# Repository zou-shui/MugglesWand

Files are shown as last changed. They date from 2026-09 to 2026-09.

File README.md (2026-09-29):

# Muggles' Wand - 基于TinyML的动力学手势分类魔杖

立创开源平台链接：[Muggles' Wand - 给麻瓜设计的魔杖 - 立创开源硬件平台](https://oshwhub.com/zoushui/project_zfbqlpxs)

## 项目简介

这是一根魔杖，但，是给麻瓜[^1]用的。

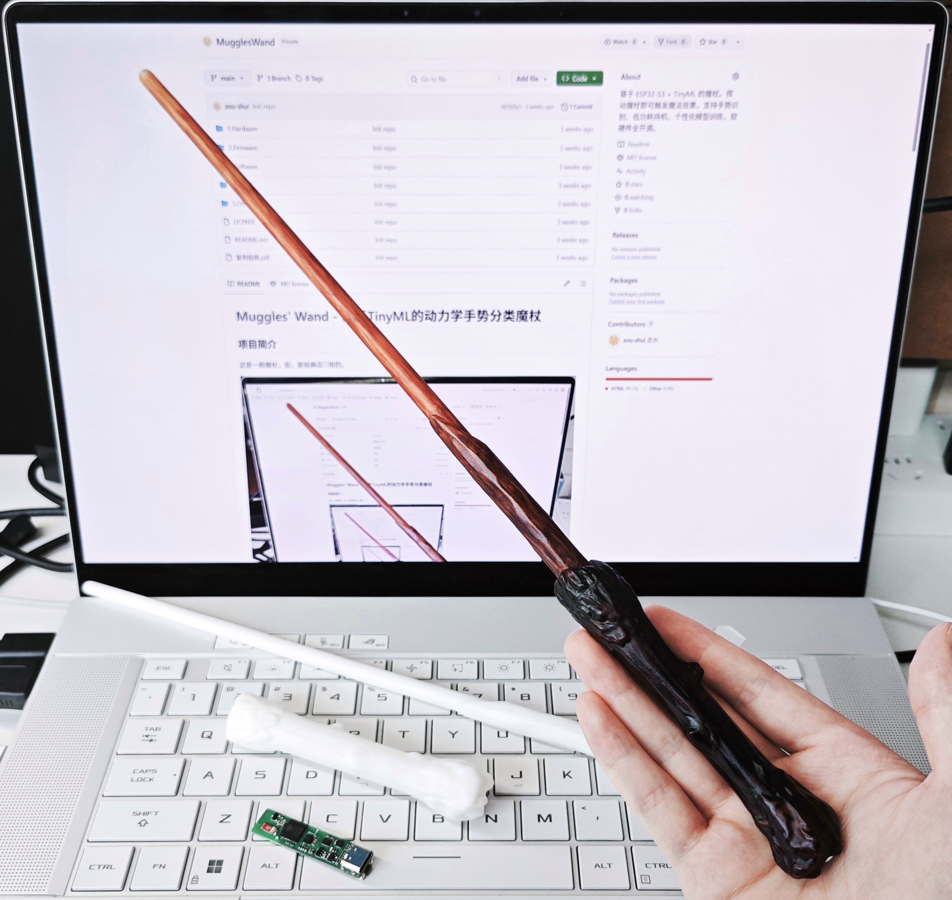
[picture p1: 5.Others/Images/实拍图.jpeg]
魔杖实物图


在哈利波特初代魔杖模型中嵌入ESP32-S3、六轴 IMU 和神经网络模型，麻瓜无需魔法，只需标准地挥动魔杖，即可触发专属的“魔法效果”（如Lumos[^2]、模拟键鼠、光绘效果等）。

## 视频链接

[【开源】给麻瓜的魔杖](https://www.bilibili.com/video/BV14XaJ6nEzr/?share_source=copy_web&vd_source=b9a966f3c62fa9746bb00910b5fc0d9c)

## 项目特点

- 哈利波特初代魔杖外形，内置RGB灯带提供施法光效。
- 基于ESP32-S3 + ICM42670P六轴 IMU，支持 Wi-Fi、BLE，便于扩展无线控制和交互功能。
- 精准电量 + 低功耗设计，静置待机，拿起开机，理论待机时间长达1.8年。
- 内置手势状态机自动区分有效手势和无意义挥动，无需提供显式手势开始(或结束)[^3]信号。
- 使用握持角度(姿势)无关变量训练模型，支持几乎任意握持姿角度/姿势。
- 配套上位机和魔杖Web端图形化界面，支持用户自行采集数据并训练个性化手势模型。

## 硬件架构

硬件由一块PCB + 电池 + 灯带组成。PCB集成了单片机、IMU、Type-C接口、按键以及跟电源相关的必要电路。

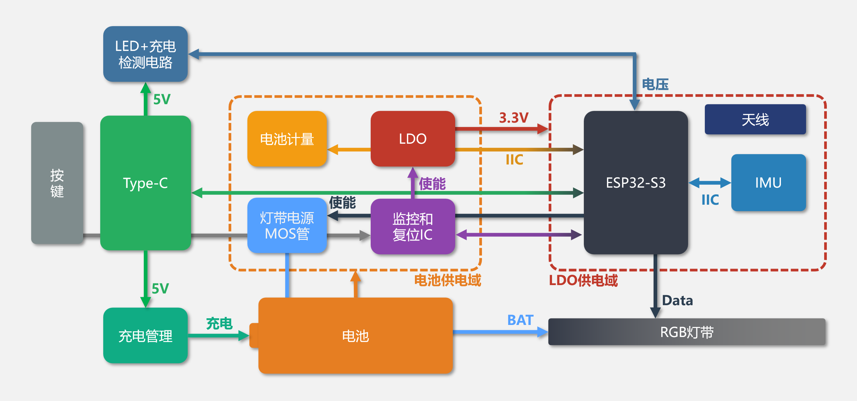
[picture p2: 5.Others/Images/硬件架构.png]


硬件位置关系及电气连接示意图如下。

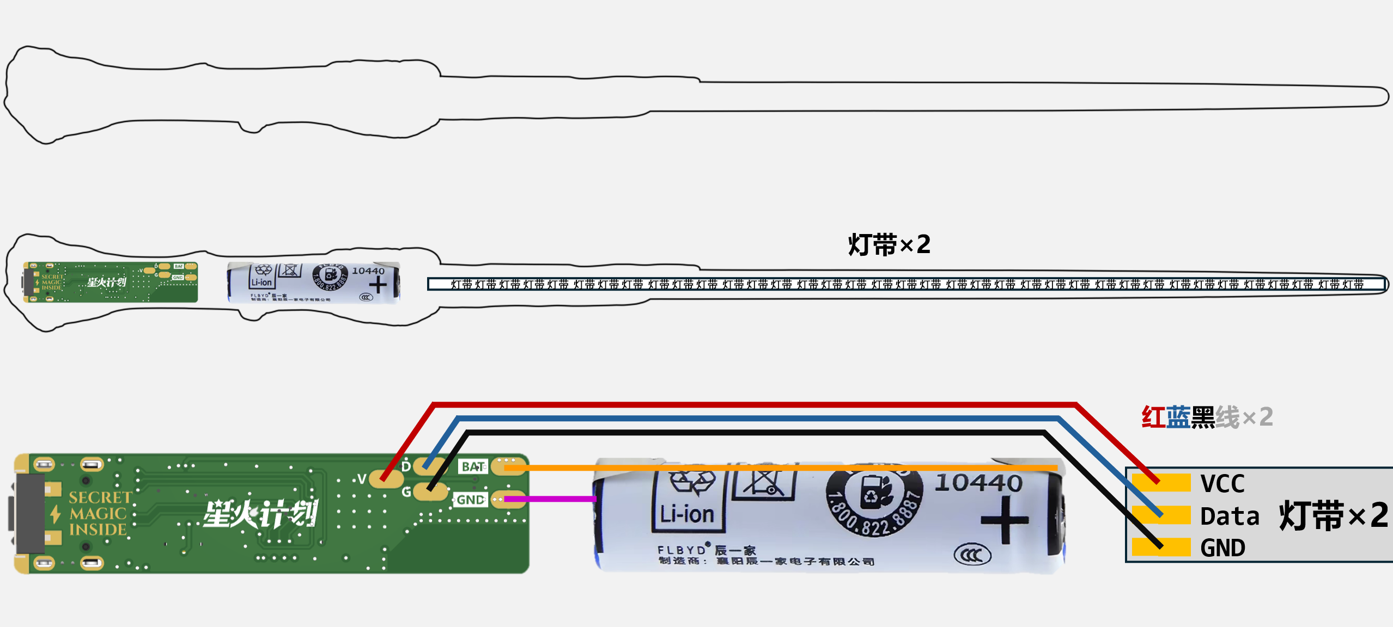
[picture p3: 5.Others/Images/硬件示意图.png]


## 使用方法

### 1. 基本操作

魔杖开机默认进入手势识别模式，固件内自带一个8分类的手势识别模型，识别如下手势：

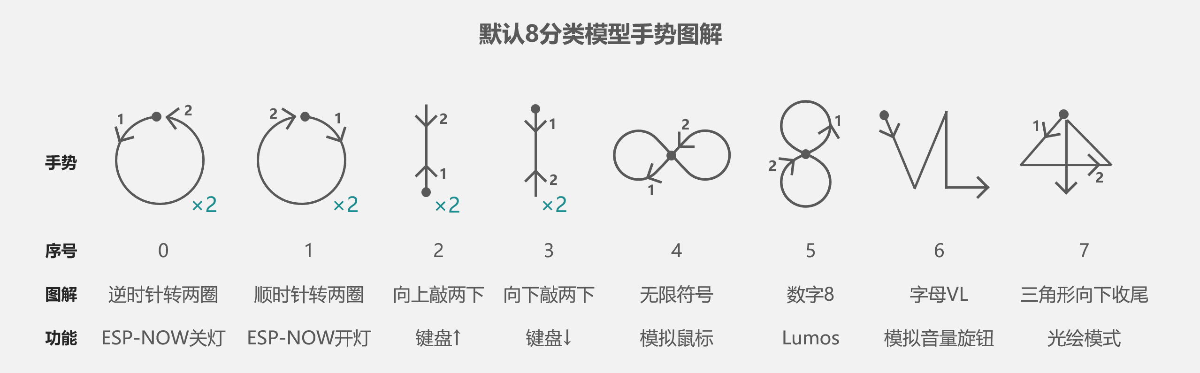
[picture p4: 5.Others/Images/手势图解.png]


只需要使用魔杖尖端在空中绘制出图形，就会触发对应的功能。挥动时间应≤1s，每个手势具体执行的功能可通过修改固件来自定义。

- ESP-NOW开关灯需要另一个接舵机的ESP32-S3开发板来执行动作，配套代码已开源在`2.Firmware`。
- 模拟键盘的按键可在固件中自定义。
- 光绘模式下，魔杖会持续检测加速度并自动触发光绘。

### 2. 按键操作

魔杖仅底部有一个按键，该按键承担了开机、关机、单击、双击、三击以及强制关机的功能。

- 关机时，单击按键开机。
- 开机时，长按按键1s关机；长按5s以上可强制断电关机[^4]。
- 开机时，单击按键的语义为“返回”，例如：模拟鼠标模式会占用IMU[^5]导致手势识别暂停，只需单击按键即可退出模拟鼠标模式。
- 双击、三击按键的行为可以在固件中自定义。

### 3. 使用命令操控魔杖

魔杖底部的 Type-C 接口连接 ESP32-S3 的USB虚拟串口(USB CDC)。将魔杖连接到 PC 后，通过串口助手与魔杖交互。可以像使用终端一样给魔杖发送命令，输入`help`获取可用命令，输入`ota`进入OTA模式。（下图左）

> 命令需要以回车符结尾才会被识别，另外需要打开串口助手的DTR和RTS才能通讯。

此外如果连接了魔杖的热点(AP)，还可以使用TCP/IP串口，地址192.168.4.1:8080（下图右）。

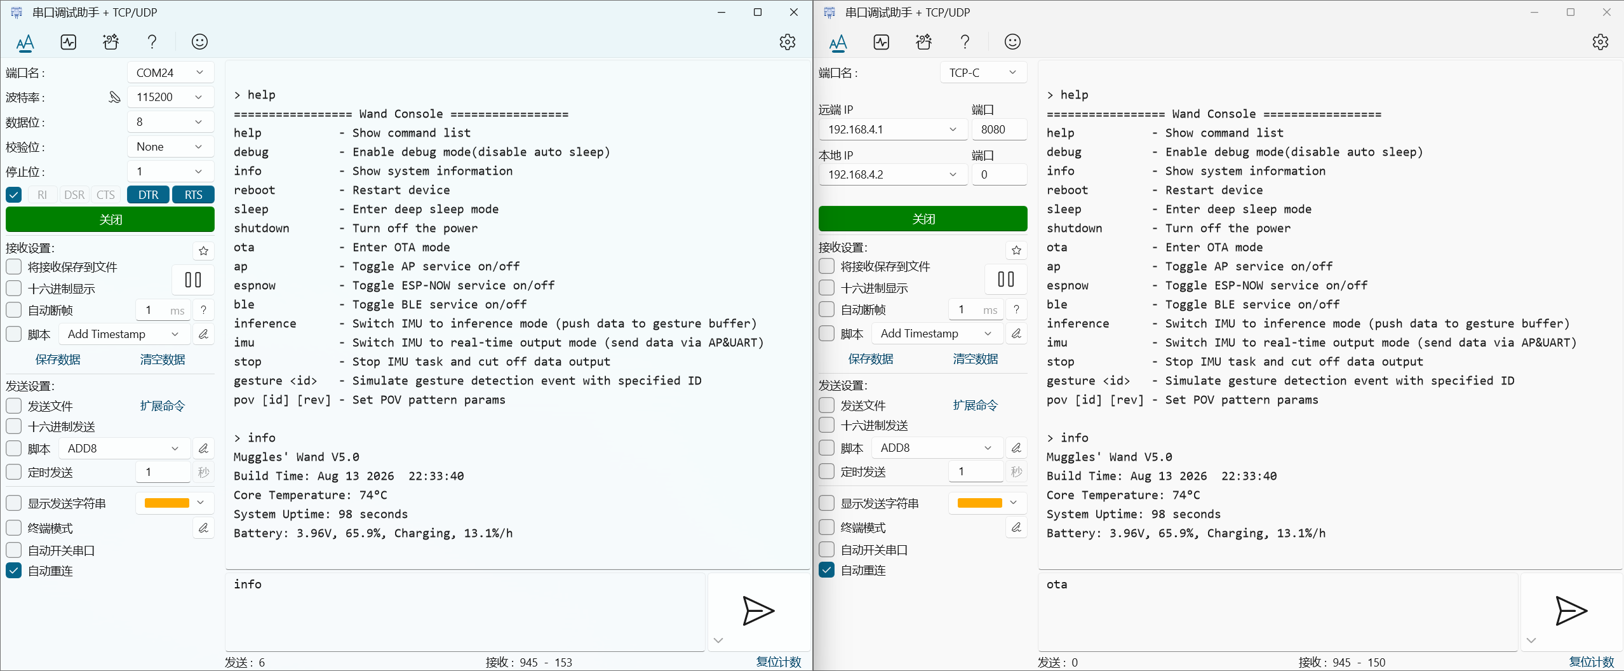
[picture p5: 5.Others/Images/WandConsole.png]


更进一步，连接魔杖热点情况下在浏览器中访问[192.168.4.1](http://192.168.4.1/)即可看到魔杖的Web端图形化界面，该界面功能和串口命令一致，但增加了IMU数据可视化。

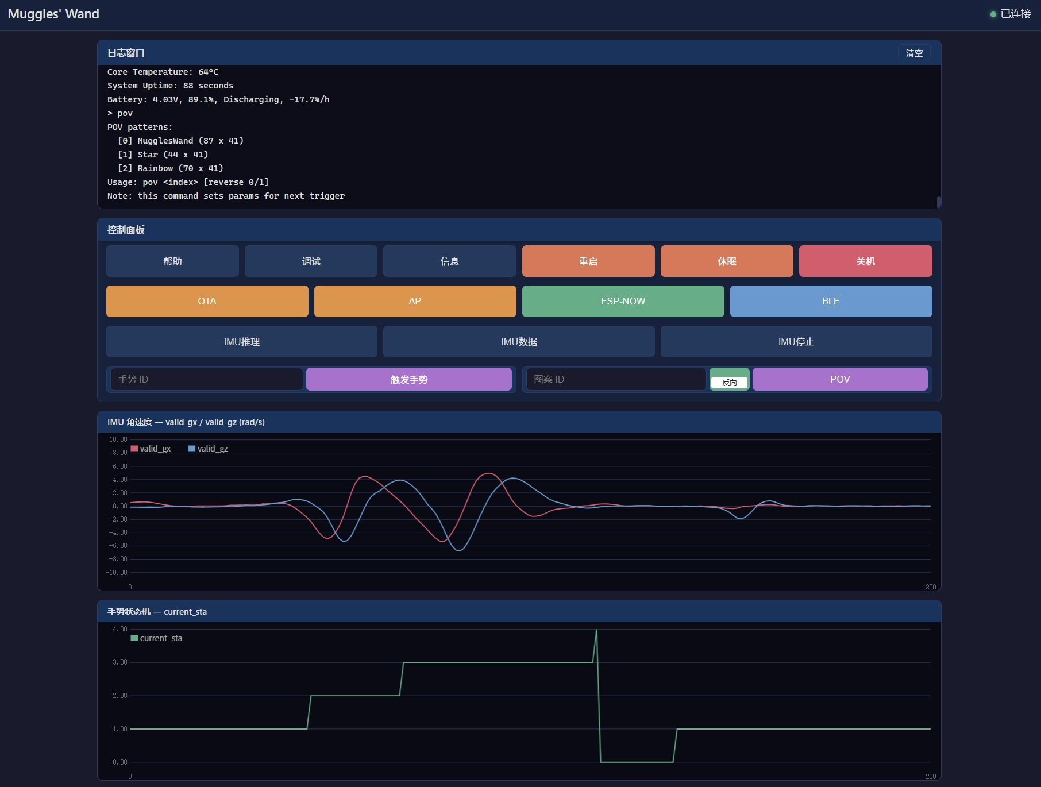
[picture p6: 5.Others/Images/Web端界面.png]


## 功耗分析

超低的待机功耗是本项目亮点之一。

在**待机状态**下，ESP32处于DeepSleep模式，系统处于运动唤醒模式，此时功耗如下表所示：

| 器件  | ESP32 | 复位IC | 电池计量 | IMU | LDO | 合计值（理论） | 实际 |
| --- | ----- | ---- | ---- | ----- | ----- | --- | ---- |
| 电流  | 7uA | 6uA  | 4uA  | 3.5uA | 1.8uA | 22.3uA  | 25uA |

实测待机功耗约 25 μA，在电池400mAh的可用容量下的理论待机时间约1.8年[^6]。

`400mAh / 0.025mA = 16000h ≈ 1.8年`

所有状态功耗情况如下表所示。

| 状态 | 功耗 | 备注 |
| --- | --- | --- |
| 关机 | 3uA | LDO输出关断，系统仅复位IC和电池计量IC耗电 |
| 待机 | 25uA | LDO输出使能，系统处于DeepSleep+运动唤醒状态 |
| 开机，关闭射频 | <100mA | - |
| 开机，开启射频 | <200mA | 实测续航约为2h |

由于灯带耗电量较高，故在光绘模式下续航可能无法达到2h。

## 上位机与模型训练

默认模型的训练数据有限，不同用户的挥动习惯可能导致识别准确率下降，也就是魔杖出现了“认主”现象。`3.Software`下提供数据采集工具和 TensorFlow 模型训练代码，用户可以自行采集数据并训练个性化模型，给魔杖“易主”。

另外，还提供将任意图片转换为光绘数组的上位机工具`POVTool`，自定义专属光绘图案。

## 复刻

由于固件源码以 Git 子模块方式管理，克隆项目时需要加上 `--recurse-submodules` 参数：

```bash
git clone --recurse-submodules https://github.com/zou-shui/MugglesWand.git
```

复刻可参考根目录下的[复刻指南.PDF](./复刻指南.pdf)，步骤包括硬件复刻、固件烧录、封装、上色和喷漆。

项目结构：

```
MugglesWand
 ├── 1.Hardware/      PCB工程、原理图、制版文件
 ├── 2.Firmware/      ESP32-S3固件及源码
 │   ├── MugglesWand-src/         魔杖源码（子仓库）
 │   ├── MugglesWand-firmware/    魔杖固件
 │   └── EspNow_Slave-src/        ESP-NOW舵机开关灯执行器源码
 ├── 3.Software/      数据采集、训练及上位机工具
 ├── 4.Model/         魔杖外壳模型
 ├── 5.Others/        数据手册、图片
 ├── 复刻指南.pdf
 └── README.md
```

[^1]: 麻瓜，英文Muggle，指不会魔法的普通人

[^2]: Lumos，魔杖照明咒，是一个可以点亮魔杖头、用来在黑暗中照明的魔咒

[^3]: 传统基于 IMU 的手势识别通常需要额外输入信号标记手势开始或结束。本项目通过手势状态机自动检测有效手势，从而无需额外的开始/结束按键。

[^4]: 强制关机是硬件级的，会直接关断LDO输出

[^5]: 不止模拟鼠标模式会占用IMU，模拟音量旋钮以及光绘模式都会占用IMU

[^6]: 魔杖所使用电池的额定容量为450mAh，但监控复位IC(STM6601)会在电池3.1V以下时关断LDO并无法再次开机，所以估计电池可用容量为400mAh。另外由于电池自放电等因素影响，实际待机时间可能会更短。

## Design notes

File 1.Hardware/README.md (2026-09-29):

# Hardware

本目录存放PCB工程文件、Gerber文件、原理图以及BOM表。

工程文件后缀名为`.epro2`，使用立创EDA专业版打开，打开方式为：文件 -> 导入 -> 嘉立创EDA专业版。

## 下单注意事项

板厚务必选择**1.0mm**；另外天线的走线做了50Ω阻抗匹配，下单时请按照图中红框选择。

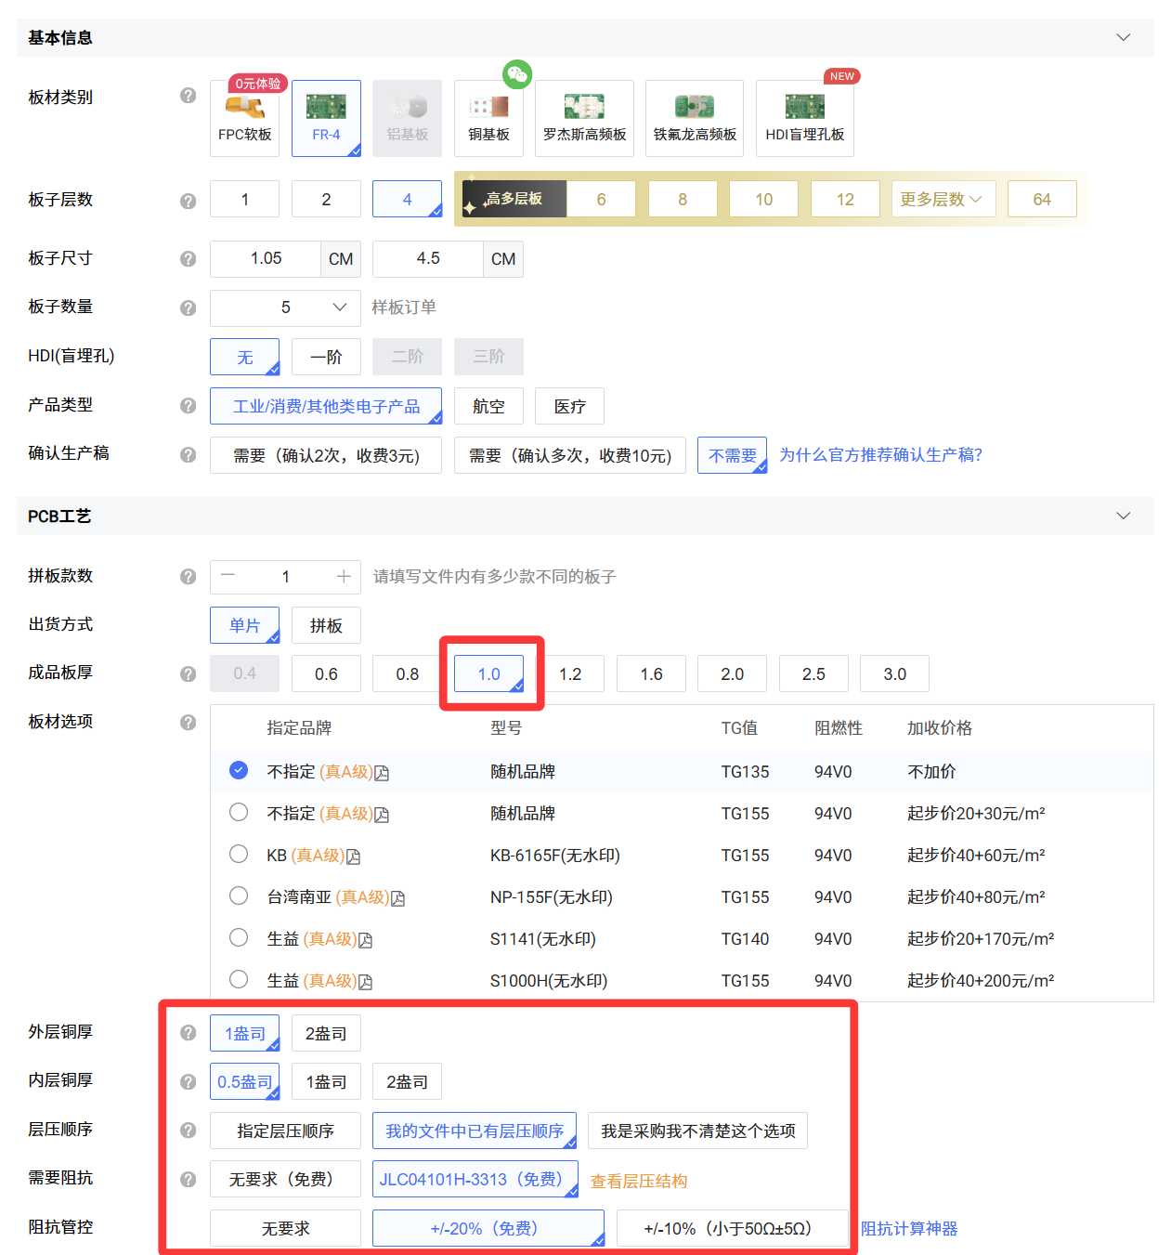
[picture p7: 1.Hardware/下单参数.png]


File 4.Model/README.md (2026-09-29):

# Model

本目录存放魔杖的模型文件，包含Blender原工程和导出的STL文件，可直接使用STL文件进行3D打印。

## 下单注意事项

使用以下参数打印

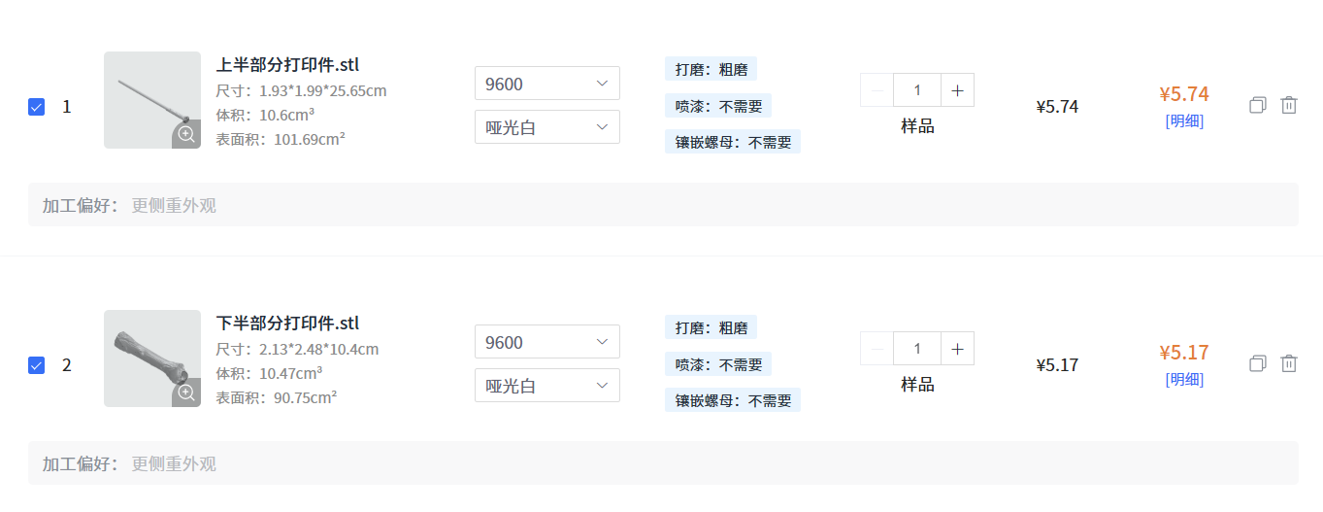
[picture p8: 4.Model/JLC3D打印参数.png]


另外由于**上半部分打印件**为细长中空盲孔模型，打印件可能会出现以下问题：

* 因模型45°摆放打印导致**打印件弯曲**

* 中空部分**残留树脂**，导致灯带无法塞入

为尽可能避免上述问题，请在下单前备注以下内容：

```
上半部分打印件需要竖直摆放进行打印，发货前请确保中空孔洞内干净无残留液体。
下半部分打印件无特殊要求。
```

## 模型说明

魔杖模型来源于[🪄 harry potter magic wand prop・Free OBJ File for ・Cults](https://cults3d.com/en/3d-model/game/harry-potter-magic-wand-prop)，经过微调、切割和挖空之后导出为STL文件，具体可查看Blender工程。

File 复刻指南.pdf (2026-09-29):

# Muggles’ Wand

# 复刻指南

# VERSION: 2026-9-29 Copyright © 2026 zoushui

感谢您对本项目的支持！Muggles’ Wand 以哈利波特使用的初代魔杖模型为原型，使用 光固化 3D 打印魔杖实体，在其内嵌入现代科技制成。因为是给麻瓜制作的魔杖，故命名为

## Muggles’ Wand。

复刻有一定的难度，建议通览整个项目资料、确定可行性之后再开始。

1 准备工作

正式开始制作前，请准备以下工具、材料及电子元器件。

准备工具：加热台及锡膏、电烙铁及焊锡丝、镊子、502 胶水、704 有机硅密封胶。

## 1. PCB 打样，板厚选择 1.0mm。

2. 根据 BOM 表购买所需元器件。
3. 打印魔杖模型，打印材料选树脂 9600。
4. 购买锂电池、漆包线、灯带，其具体参数如下：
物料 | 参数 | 实物图

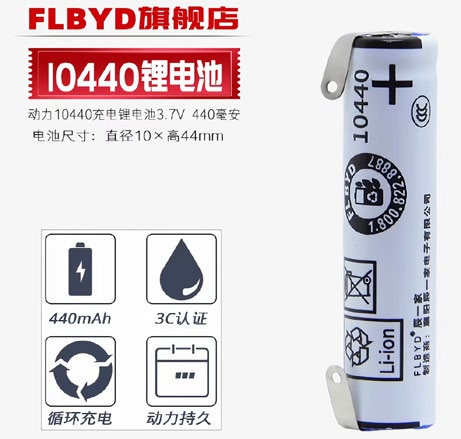
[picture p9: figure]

锂电池

额定电压 3.7V
尺寸 10440

## (直径 10mm 长度 44mm)

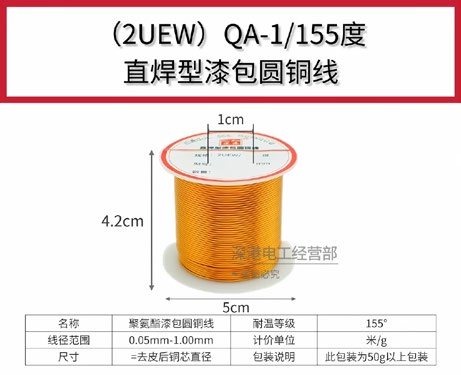
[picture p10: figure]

## QA 漆包线 直径 0.3mm

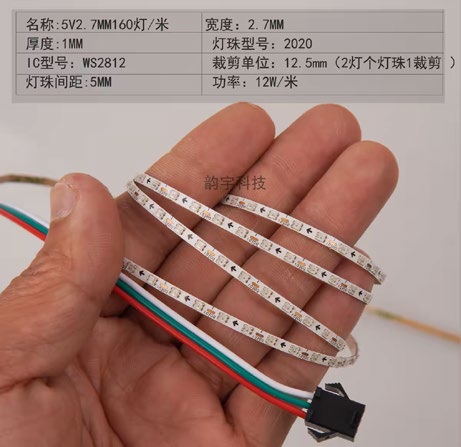
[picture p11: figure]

WS2812
可编程灯带

额定电压 5V

## 宽度 2.7mm

灯珠密度 160 灯/米

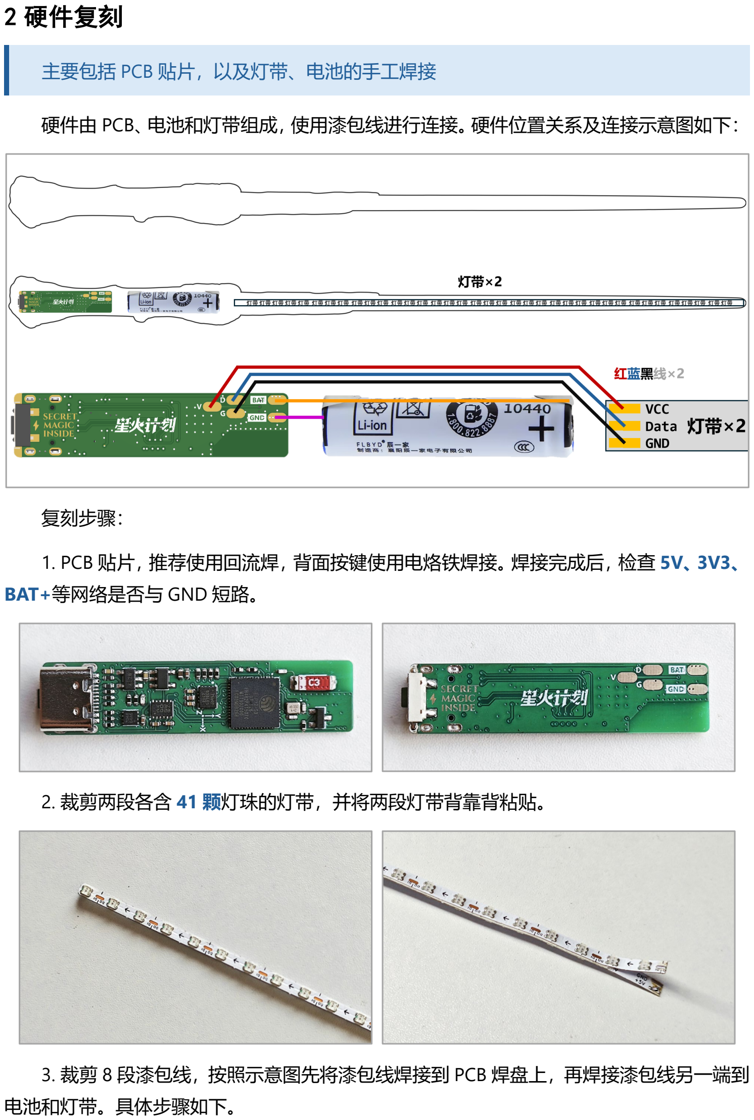
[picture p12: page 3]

2 硬件复刻

主要包括 PCB 贴片，以及灯带、电池的手工焊接

硬件由 PCB、电池和灯带组成，使用漆包线进行连接。硬件位置关系及连接示意图如下：

复刻步骤：
1. PCB 贴片，推荐使用回流焊，背面按键使用电烙铁焊接。焊接完成后，检查 5V、3V3、 BAT+等网络是否与 GND 短路。
2. 裁剪两段各含 41 颗灯珠的灯带，并将两段灯带背靠背粘贴。
3. 裁剪 8 段漆包线，按照示意图先将漆包线焊接到 PCB 焊盘上，再焊接漆包线另一端到 电池和灯带。具体步骤如下。

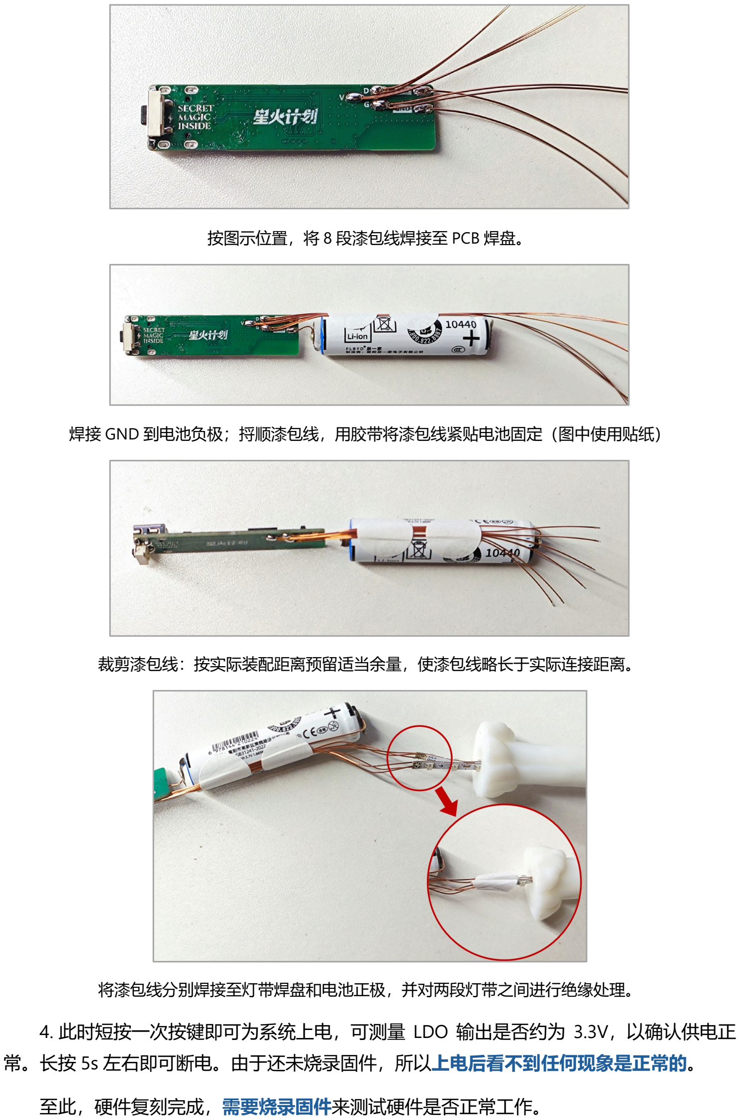
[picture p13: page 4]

按图示位置，将 8 段漆包线焊接至 PCB 焊盘。

焊接 GND 到电池负极；捋顺漆包线，用胶带将漆包线紧贴电池固定（图中使用贴纸）

裁剪漆包线：按实际装配距离预留适当余量，使漆包线略长于实际连接距离。

将漆包线分别焊接至灯带焊盘和电池正极，并对两段灯带之间进行绝缘处理。
4. 此时短按一次按键即可为系统上电，可测量 LDO 输出是否约为 3.3V，以确认供电正 常。长按 5s 左右即可断电。由于还未烧录固件，所以上电后看不到任何现象是正常的。

至此，硬件复刻完成，需要烧录固件来测试硬件是否正常工作。

3 固件烧录

向 ESP32 内烧录固件并测试硬件是否正常

使用 USB 烧录前，确保电池已连接，且系统处于关机状态（LDO 无 3.3V 输出）。使用镊 子将按键外壳的金属部分（BOOT）与 GND 短接，例如接触 Type-C 外壳。保持短接，同时短 按按键使 ESP32 上电。随后通过 USB 连接 PC，设备管理器出现新的串口号后即可开始烧录。

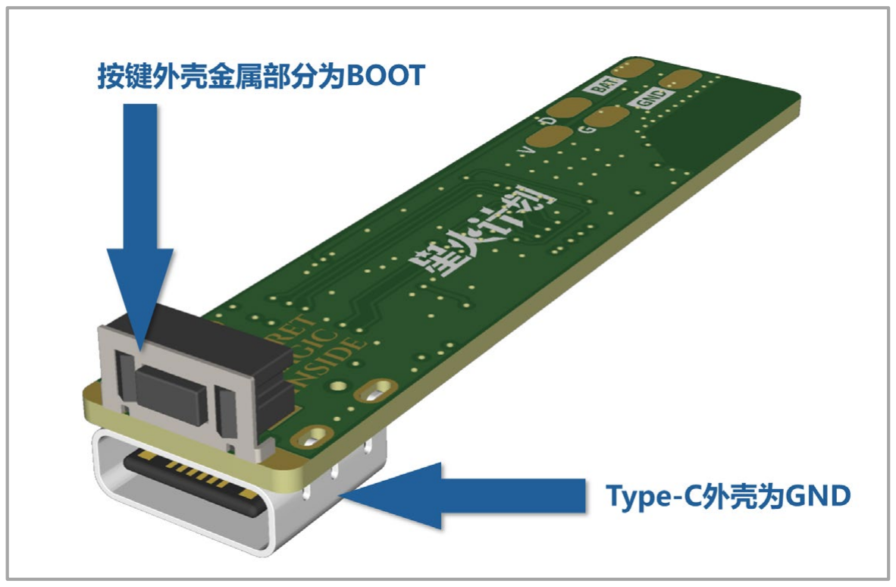
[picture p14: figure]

有两种烧录方式可选择，推荐使用 PlatformIO 烧录。

- PlatformIO 烧录：点击烧录按钮，PlatformIO 通常会自动识别设备串口并开始烧录。

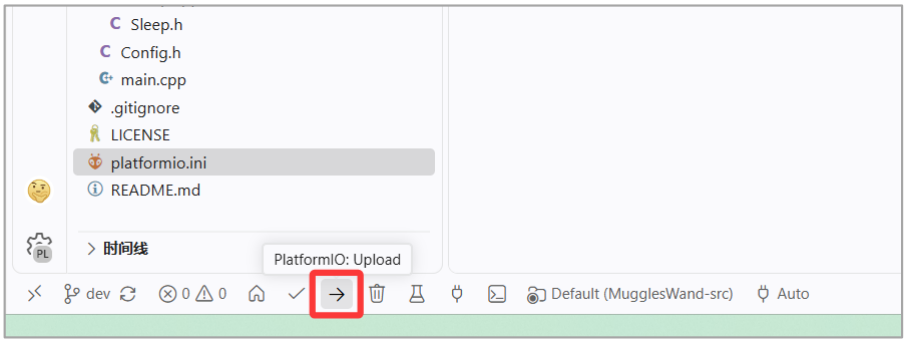
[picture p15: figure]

- 使用烧录工具烧录：使用乐鑫官方烧录工具 flash_download_tool(点击跳转下载链接) (https://docs.espressif.com/projects/esp-test-tools/zh_CN/latest/esp32/production_stage/tools/flash_download_tool.html)

## 烧录 2.Firmware/MugglesWand-firmware 下的三个 bin 文件，该文件夹下附带有具体操作截

图可参考。另外可参考官方的烧录步骤。 (https://docs.espressif.com/projects/esp-test-tools/zh_CN/latest/esp32/production_stage/tools/flash_download_tool.html)
固件烧录完成后，长按按键 5s 以上关机，再短按开机，程序即可运行。需要测试硬件和 各功能是否正常，都正常即可进入下一步封装。

由于封装过程不可逆，故需要确保硬件和功能全部正常才可以进入下一步封装。

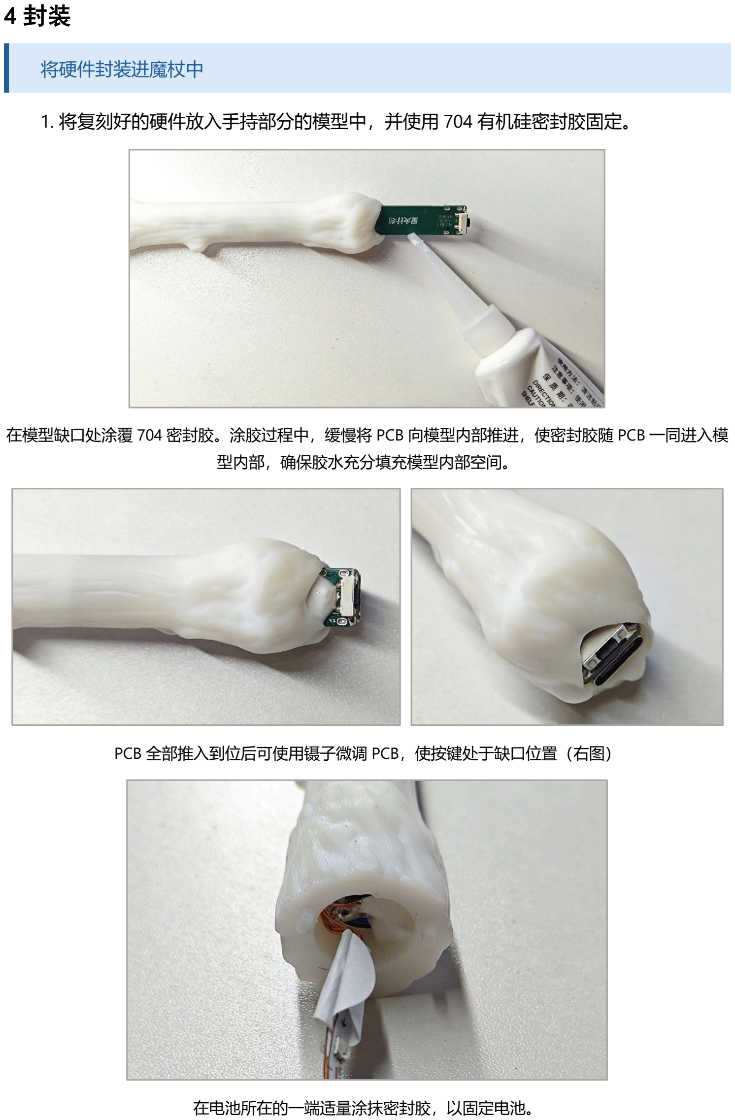
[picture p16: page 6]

4 封装

将硬件封装进魔杖中

1. 将复刻好的硬件放入手持部分的模型中，并使用 704 有机硅密封胶固定。

在模型缺口处涂覆 704 密封胶。涂胶过程中，缓慢将 PCB 向模型内部推进，使密封胶随 PCB 一同进入模 型内部，确保胶水充分填充模型内部空间。

PCB 全部推入到位后可使用镊子微调 PCB，使按键处于缺口位置（右图）

在电池所在的一端适量涂抹密封胶，以固定电池。

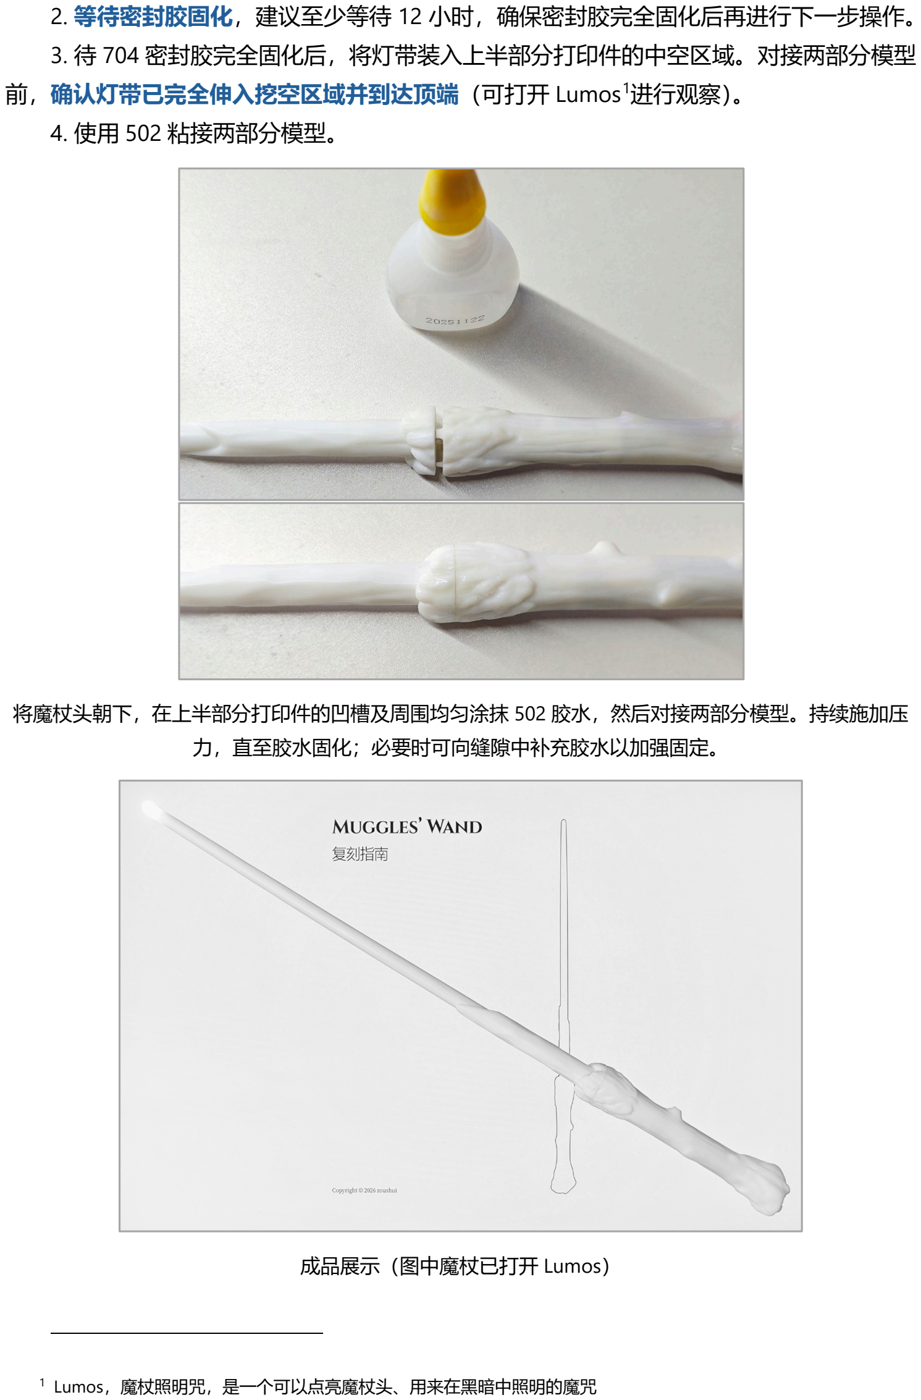
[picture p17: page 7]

2. 等待密封胶固化，建议至少等待 12 小时，确保密封胶完全固化后再进行下一步操作。
3. 待 704 密封胶完全固化后，将灯带装入上半部分打印件的中空区域。对接两部分模型 前，确认灯带已完全伸入挖空区域并到达顶端（可打开 Lumos¹
进行观察）。
4. 使用 502 粘接两部分模型。

将魔杖头朝下，在上半部分打印件的凹槽及周围均匀涂抹 502 胶水，然后对接两部分模型。持续施加压 力，直至胶水固化；必要时可向缝隙中补充胶水以加强固定。

成品展示（图中魔杖已打开 Lumos）

1 Lumos，魔杖照明咒，是一个可以点亮魔杖头、用来在黑暗中照明的魔咒

5 魔杖上色及喷漆

为封装好的魔杖上色和喷漆

封装完成之后，魔杖已经可以使用了，如需进一步提高还原度，可对模型进行上色。以 下上色及喷漆方案经过实际验证，可供参考。

5.1 模型上色
使用棕色系油性马克笔上色（更贴近木头的颜色）。需要 3 种由浅到深的棕色系马克笔， 从魔杖头到手持部分颜色逐渐变深。

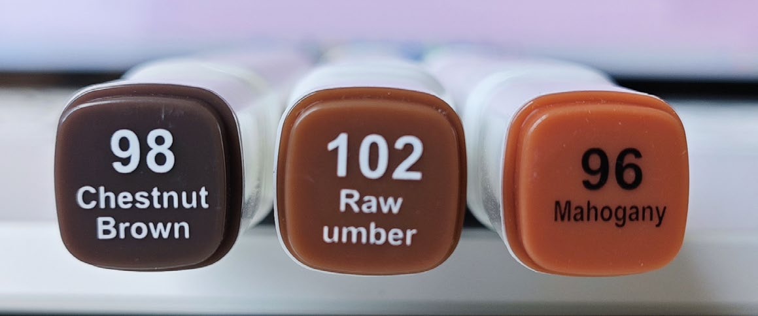
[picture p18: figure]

色号供参考
为了尽可能减小对”Lumos”亮度的影响，推荐魔杖头只上一层薄薄的颜料即可。

5.2 模型喷漆
使用油性马克笔上色完成后，等待其充分干燥。即使表面已经干燥，油性马克笔涂层仍 可能出现黏手、掉色等情况，这与其涂层特性有关。推荐使用 B603 水性消光透明保护漆在 外部喷一层漆，可以解决掉色和黏手的问题。

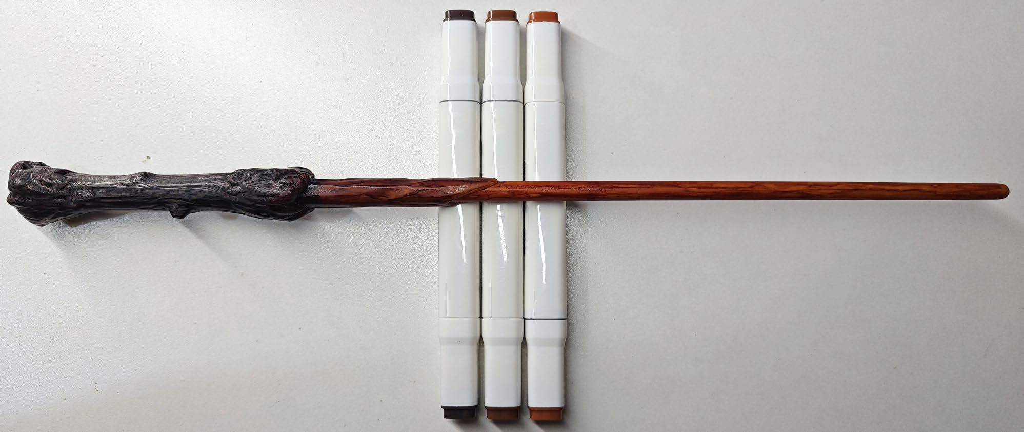
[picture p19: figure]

成品展示

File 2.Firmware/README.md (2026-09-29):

# Firmware

本目录存放 Muggles' Wand 固件及源码，源码`MugglesWadn-src`请参见子仓库[MugglesWand-src](https://github.com/zou-shui/MugglesWand-src)。

`MugglesWand-firmware`文件夹下存放子仓库**main分支**中最新的代码编译的固件，烧录方式请参考`复刻指南.PDF`第3节内容。

`EspNow_Slave-src`为基于ESP-NOW的舵机开关灯执行器的源码，运行在一块ESP32-S3-Zero开发板上。

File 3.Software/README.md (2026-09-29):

# Software

本目录存放在PC上运行的Python脚本和tf模型

## 1.OriginalData

内有DataCollector脚本源码以及打包好的可执行文件`DataCollector.exe`，后者可直接运行（无需Python环境）。

另外附有固件中模型的原始数据（csv）。

## 2.TensorFLow

内有利用原始数据对模型进行训练的程序`train.py`。需要自行配置python环境后运行。详细步骤请参阅内部的`README.md`。

## 3.POVTool

该工具是一个带有UI的可视化上位机，用于将任意图片转换成数组，供光绘模块使用。需要自行配置python环境后运行，详细步骤请参阅内部的`README.md`。

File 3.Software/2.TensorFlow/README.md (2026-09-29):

# train.py 简介

`train.py` 用于训练手势识别模型，主要特点：

- **自动识别数据集**：自动读取同目录下所有 `N.csv` 文件（`N` 为从 0 开始连续的整数），文件名即手势类别编号，支持自定义任意数量的手势类别。
- **数据格式**：每行一个样本，格式为 `label, x0, y0, x1, y1, …, x99, y99`，即 100 个时刻的 2 轴数据；脚本会校验行内标签与文件名一致，不符则终止。
- **网络结构**：轻量 1D-CNN（2 层卷积 + 批归一化 + 池化 + 全连接），配合 EarlyStopping 防止过拟合，PC 上即可快速训练。
- **自动量化**：训练完成后自动转为 INT8 全整数量化模型 `gesture_model.tflite`，并在终端输出归一化参数 `mean` / `std`，供固件端推理使用。

## 运行脚本

TensorFlow需要python3.9，需先安装该版本的Python。

用python3.9创建虚拟环境：

```bash
py -3.9 -m venv tf_env
```

激活虚拟环境：

```bash
tf_env\Scripts\activate
```

安装依赖：

```bash
pip install -r requirements.txt
```

运行脚本（运行之前请先将训练数据放在train.py同级目录）：

```bash
python train.py
```

模型训练好后会输出归一化参数`mean`和`std`到终端、生成模型文件`gesture_model.tflite`到根目录。后者需要在git bash中使用以下命令将其转换为字节数组：

```bash
xxd -i gesture_model.tflite > gesture_model.h
```

之后即可替换原固件中的模型，需要替换的地方有：

`src/Model/gesture_inference.cpp`中的**归一化参数**和**输出类别数量**

`src/Model/gesture_model.h`整个文件替换为新的`gesture_model.h`

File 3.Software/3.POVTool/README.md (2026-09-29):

# MugglesWand POV 光绘图案生成器（上位机）

把任意图片转换为固件 POV 光绘模块（`src/APP/APP_POVPatterns.h`）所需的
`CRGB[rows][cols]` 图案数组，并实时预览点阵效果与魔杖挥舞路径。

## 目录结构

```
POVTool/
├── main.py              # 入口: python main.py
├── gui.py               # PySide6 界面（点阵预览 + 挥舞动画）
├── core.py              # 转换核心: 加载/去背景/缩放/方向映射/自动比例
├── exporter.py          # CRGB 代码生成 + 固件头文件插入
├── requirements.txt
└── wand_lineart.png     # 挥舞动画素材（灯带区域: 横向像素 x=30~1310）
```

## 运行上位机

**1.（可选）创建虚拟环境**

虚拟环境可隔离本项目依赖，避免污染系统 Python；跳过此步则直接全局安装。

```bash
python -m venv .venv
```

激活虚拟环境（Windows）：

```bash
.venv\Scripts\activate
```

> 激活后命令行提示符前会出现 `(.venv)`；之后步骤的命令均在虚拟环境中执行。

**2. 安装依赖**

```bash
pip install -r requirements.txt
```

**3. 启动上位机**

```bash
python main.py
```

## 上位机使用说明

1. **导入图片**：点击「选择图片…」或直接拖入窗口（支持 PNG/JPG/BMP/WebP/GIF）。
   导入时按图片宽高比自动调整行数，并自动开始播放预览（100% 速度 = 固件 10ms/帧）。
2. **图案参数**：
   - **图案名**：仅限英文/数字/下划线（C 标识符），含中文会实时警告
   - **列数(LED)**：灯带 LED 数量，固件固定为 41；改变列数时行数按比例联动
   - **行数(帧)**：播放帧数，决定图案高度与播放时长（行数 × 10ms）
   - **扫描方向**：杖水平从上往下挥 / 杖竖直从左往右挥，切换时按图片比例动态调整行数
   - **左右镜像**：杖水平时 LED 列反序；杖竖直时改为从右往左挥
   - **去除背景**：取四角平均色，容差内视为透明（白底/纯色底图片常用）
3. **预览**：「挥舞动画」页用 `wand_lineart.png` 渲染真实的挥舞路径与拖尾；「点阵预览」页显示空间效果图案。
4. **导出**：
   - **复制 CRGB 代码**：图案块 + 注册行，格式与 `APP_POVPatterns.h` 一致
   - **保存完整头文件**：可直接编译
   - **插入固件头文件**：一键写入，自动备份 `.bak`，同名图案整体替换

## 打包成 exe（分发到无 Python 的电脑）

**1.（可选）创建虚拟环境**（同上；已创建过可跳过）

```bash
python -m venv .venv
.venv\Scripts\activate
```

**2. 安装 PyInstaller**

```bash
pip install pyinstaller
```

**3. 打包**

```bash
pyinstaller --noconfirm --clean --onefile --windowed --name MugglesWandPOVTool --add-data  "wand_lineart.png;." main.py
```

产物：`dist/MugglesWandPOVTool.exe`（单文件，约 65MB），目标电脑无需安装
Python，双击即用。

要点：

- `--onefile` 单文件模式（首次启动解压稍慢）；若在意启动速度或杀毒误报，
  可换成 `--onedir` 目录模式
- `--windowed` 隐藏控制台窗口
- 挥舞动画素材 `wand_lineart.png` 已通过 `--add-data` 打进 exe，
  代码用 `resource_path()` 读取，源码/打包两种模式通用

## 固件对接要点

- 固件定义：`POVPatternInfo { name, data, rows, width }`，`width` = 41（`WS2812_LED_COUNT`）
- 行序约定：row 0 = 先播放（`AnimPOV` 每 10ms 推进一行，100 行/秒）
- 上位机只生成正向挥动的数组；反向挥舞（如习惯向上/向左挥杖）在固件端用
  `APP_POV_set_params(pattern, reverse)` 播放同一数组即可，无需重新生成
- 插入功能会正则定位 `kPovPatterns[]` 注册表并保持排版一致，文件有 `.bak` 备份可回滚

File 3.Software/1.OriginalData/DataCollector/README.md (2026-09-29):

# DataCollector.py 脚本

用于采集魔杖输出的数据，为后续模型训练提供数据支持。

采集前需要连接魔杖热点，脚本会访问8080端口的TCP/IP串口获取IMU输出的数据并缓存，只有在手势状态机输出4时保存最新的100帧数据到csv中。

## 若需要打包成exe，执行以下操作：

### 1.创建虚拟环境并启动（可选）

创建：

```bash
python -m venv .venv
```

启动：

```bash
.venv\Scripts\activate
```

### 2.安装pyinstaller

```bash
pip install pyinstaller
```

### 3.打包DataCollector.py

```bash
pyinstaller -F --clean DataCollector.py
```

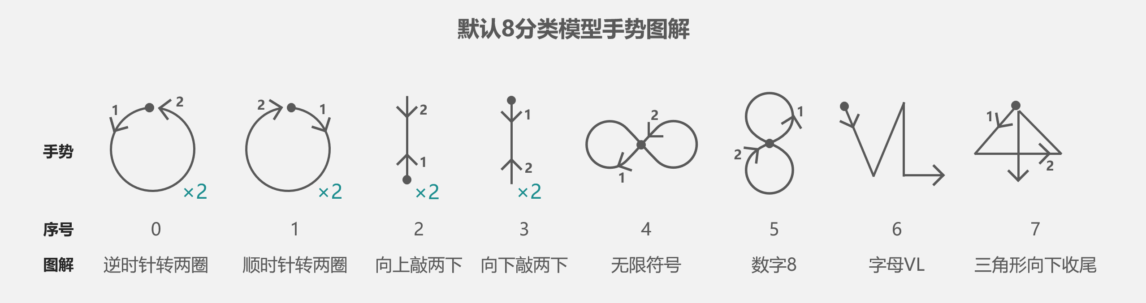
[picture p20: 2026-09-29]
3.Software/1.OriginalData/8分类手势数据集/手势图解.png

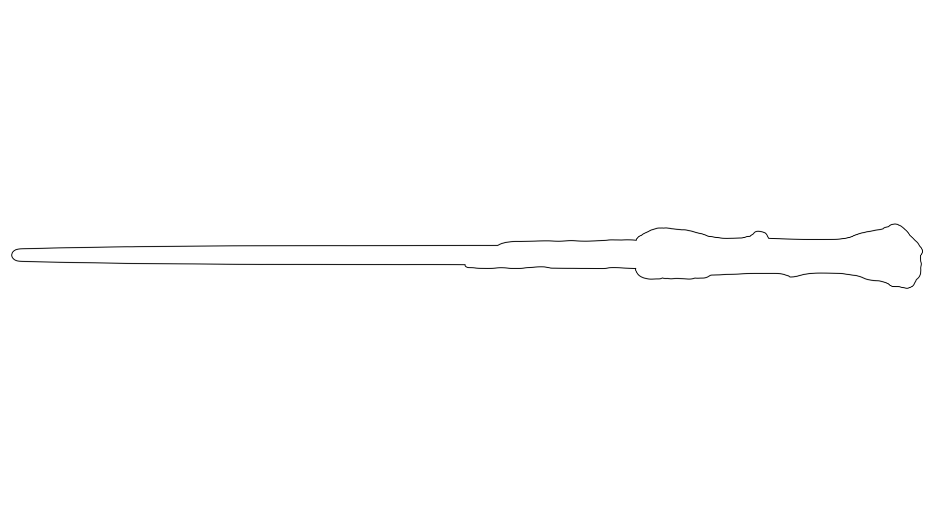
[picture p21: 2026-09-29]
3.Software/3.POVTool/wand_lineart.png

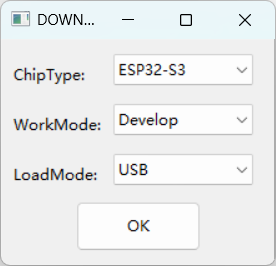
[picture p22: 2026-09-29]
2.Firmware/MugglesWand-firmware/步骤1.png

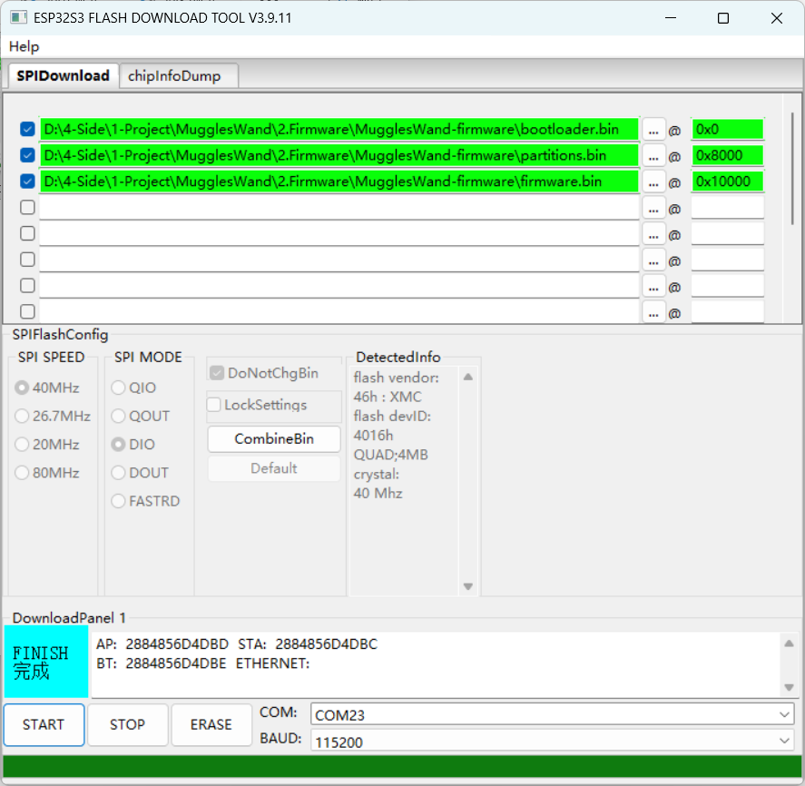
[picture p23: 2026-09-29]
2.Firmware/MugglesWand-firmware/完成.png

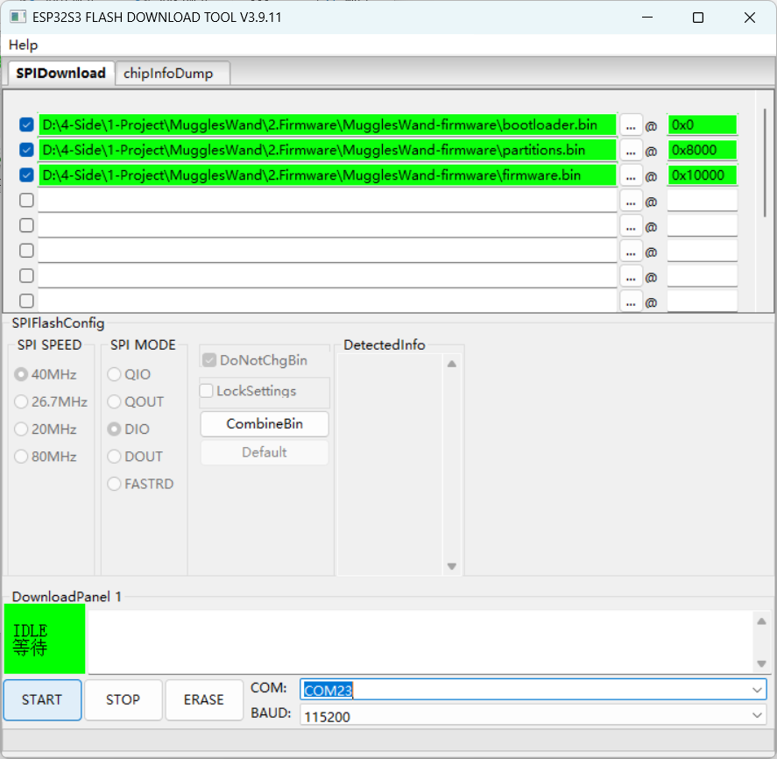
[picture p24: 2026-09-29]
2.Firmware/MugglesWand-firmware/步骤2.png

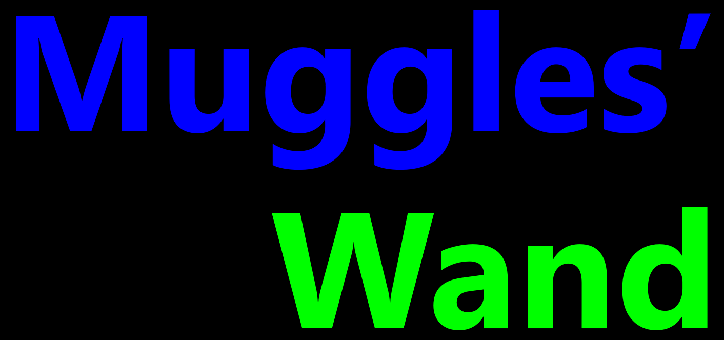
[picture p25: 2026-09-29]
3.Software/3.POVTool/光绘素材/MugglesWand.png

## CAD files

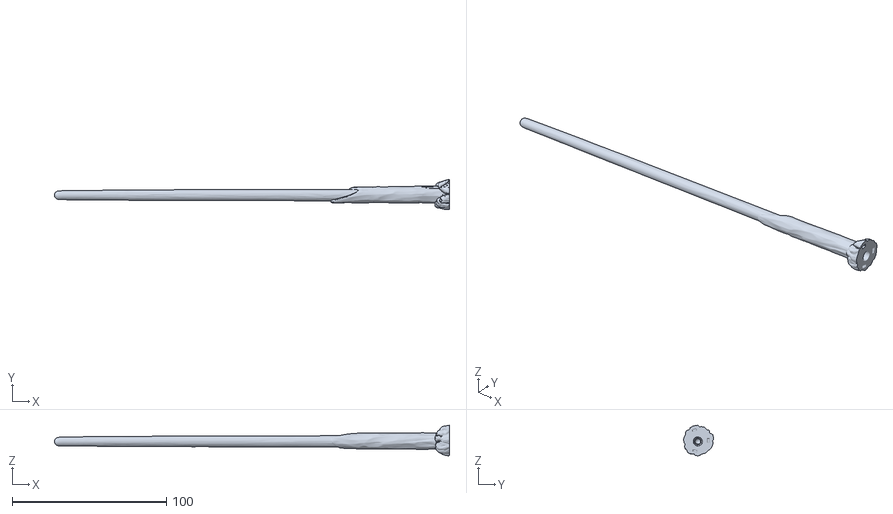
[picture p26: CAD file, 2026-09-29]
4.Model/上半部分打印件.stl
256.5 x 19.6 x 19.9

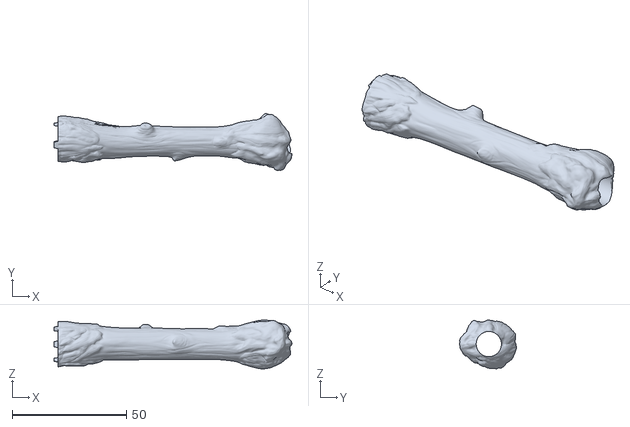
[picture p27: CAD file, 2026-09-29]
4.Model/下半部分打印件.stl
104.0 x 24.8 x 21.3

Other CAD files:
4.Model/HarryPotter' Wand.blend

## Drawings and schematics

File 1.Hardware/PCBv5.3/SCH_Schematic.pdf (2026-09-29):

# POWER

电池 | 电池计量 | 充电管理 | 按键管理和低电量保护 | 稳压3.3V

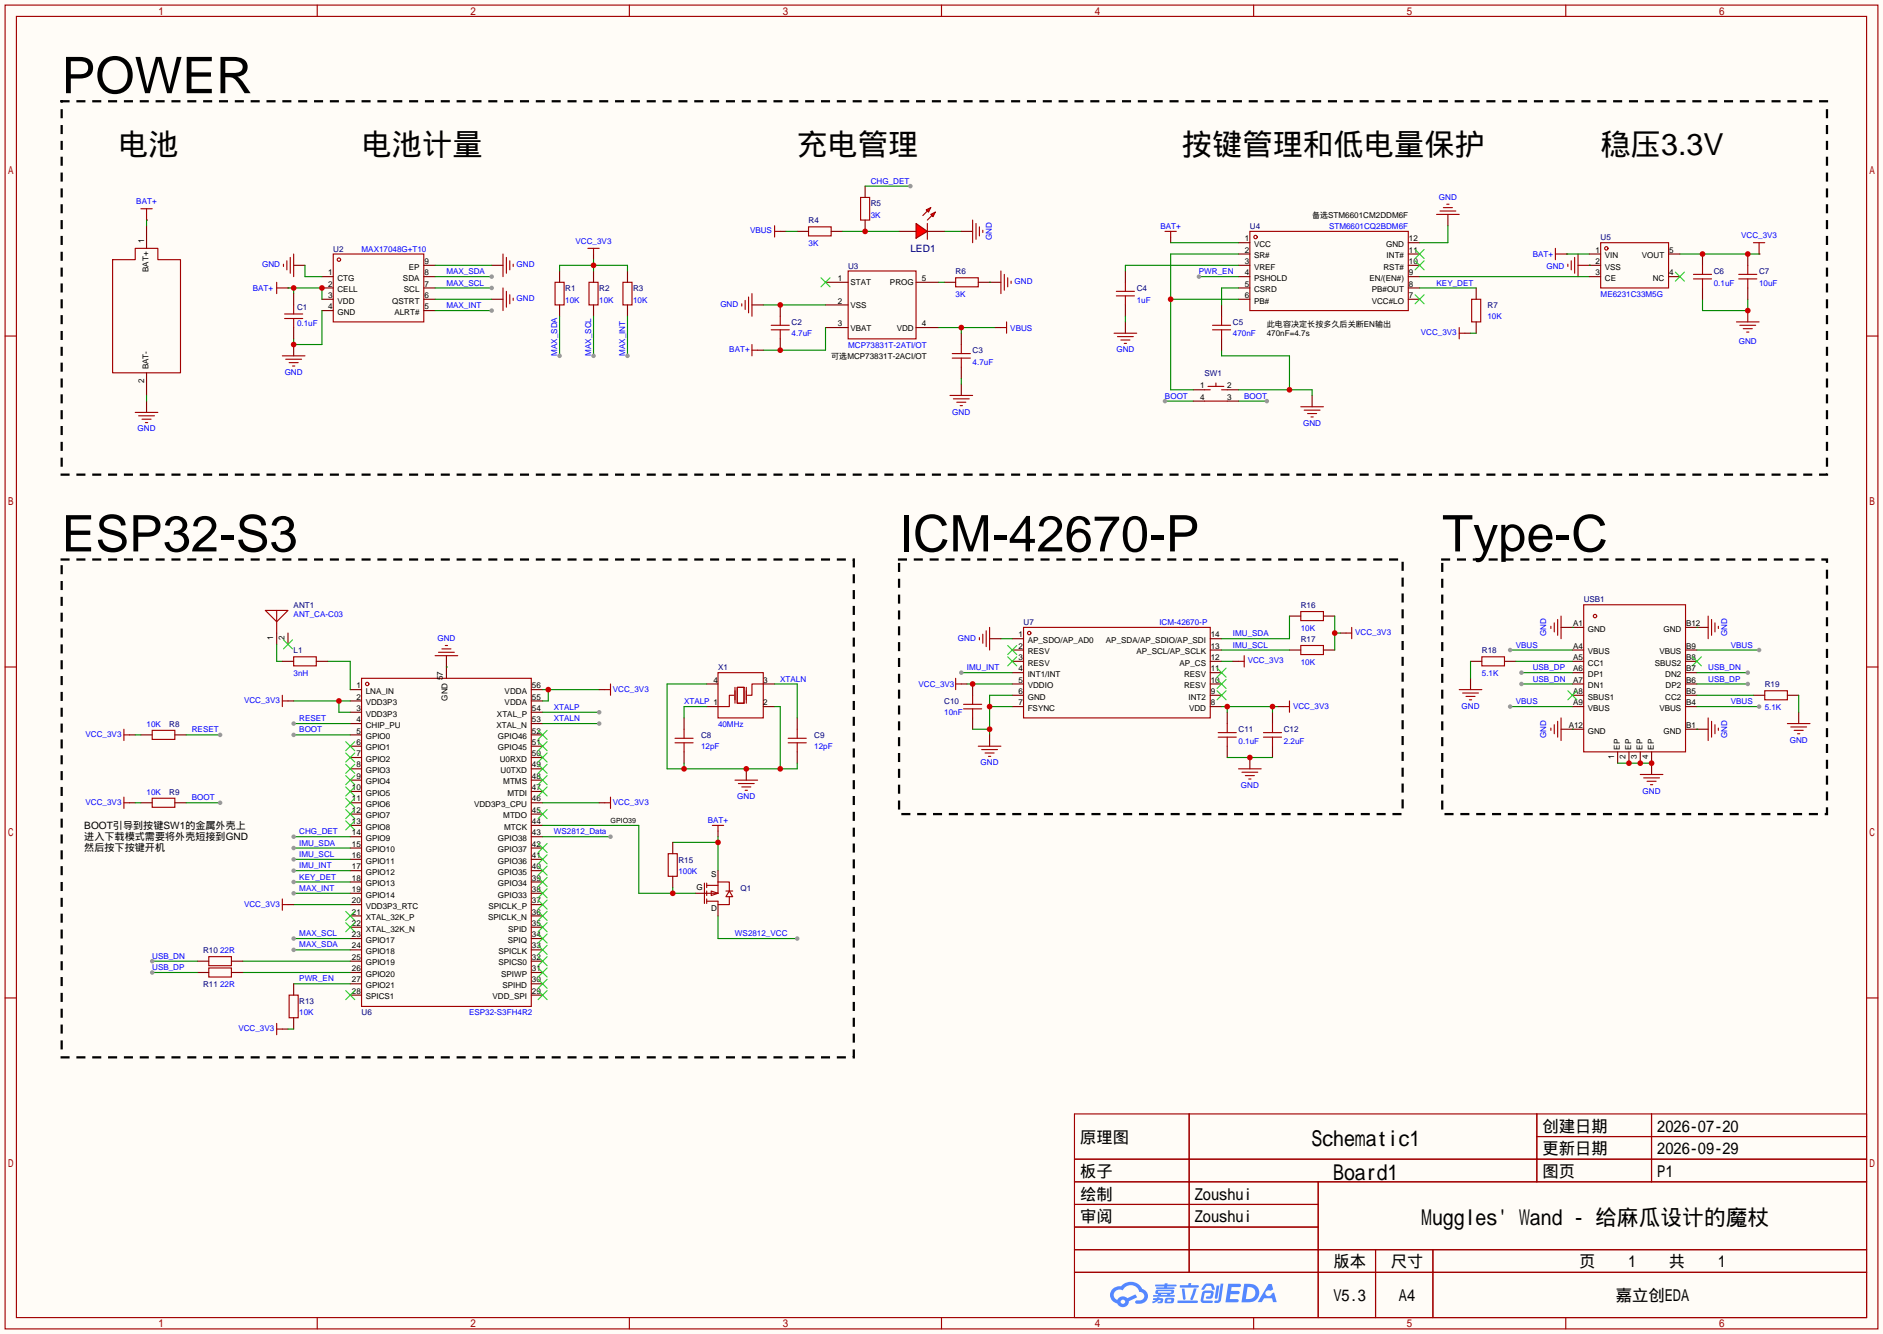
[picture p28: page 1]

原理图 | Schematic1 | 创建日期 | 2026-07-20

更新日期 | 2026-09-29

板子 | Board1 | 图页 | P1
绘制 | Zoushui | Muggles' Wand - 给麻瓜设计的魔杖
审阅 | Zoushui

V5.3 | A4 | 嘉立创EDA

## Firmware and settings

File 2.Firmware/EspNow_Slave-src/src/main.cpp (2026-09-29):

#include <Arduino.h>
#include <esp_now.h>
#include <WiFi.h>
#include <esp_wifi.h>
#include <FastLED.h> // 引入 FastLED 库
#include "ServoDriver.h"

ServoDriver wandServo;

#define CHANNEL 1
#define WAKEUP_WINDOW_MS 40       // 闪现探测窗口：只睁眼 40ms（可覆盖发送端 20ms 的心跳周期）
#define SLEEP_DURATION_SEC 1      // 休眠周期：1 秒左右
#define KEEP_AWAKE_TIMEOUT_MS 200 // 暂停休眠状态下，超过 1 秒没收到心跳则重新休眠

// WS2812 配置
#define NUM_LEDS 1
#define DATA_PIN 21
CRGB leds[NUM_LEDS];

enum MsgType
{
  MSG_HEARTBEAT = 0x01,
  MSG_SIGNAL_1 = 0x02,
  MSG_SIGNAL_2 = 0x03
};

// 使用 RTC 内存存储状态，即使 Deep Sleep 也不会丢失
RTC_DATA_ATTR bool keepAwakeMode = false;

volatile bool heartbeatReceived = false;
volatile uint32_t lastHeartbeatTime = 0; // 记录最后一次收到心跳的时间戳

// 接收回调
void OnDataRecv(const uint8_t *mac_addr, const uint8_t *data, int data_len)
{
  if (data_len == 0)
    return;
  uint8_t msgType = data[0];

  if (msgType == MSG_HEARTBEAT)
  {
    heartbeatReceived = true;
    lastHeartbeatTime = millis(); // 更新最后收到心跳的时间
  }
  else if (msgType == MSG_SIGNAL_1)
  {
    Serial.println("[ALERT] signal 1!");
    wandServo.triggerClose();
    lastHeartbeatTime = millis();
  }
  else if (msgType == MSG_SIGNAL_2)
  {
    Serial.println("[ALERT] signal 2!");
    wandServo.triggerOpen();
    lastHeartbeatTime = millis();
  }
}

void initEspNowReceiver()
{
  WiFi.mode(WIFI_STA);
  esp_wifi_set_channel(CHANNEL, WIFI_SECOND_CHAN_NONE);
  WiFi.disconnect();
  if (esp_now_init() == ESP_OK)
  {
    esp_now_register_recv_cb(OnDataRecv);
  }
}

// 封装一个进入深度休眠的函数
void enterDeepSleep()
{
  // 在全黑关闭灯珠后再去睡觉，否则灯珠会一直亮着耗电
  leds[0] = CRGB::Black;
  FastLED.show();

  esp_sleep_enable_timer_wakeup(SLEEP_DURATION_SEC * 1000000ULL);
  Serial.println("Entering Deep Sleep...");
  Serial.flush();
  esp_deep_sleep_start();
}

void setup()
{
  Serial.begin(115200);

  // 初始化 FastLED，配置为 ESP32-S3 的 GPIO21
  FastLED.addLeds<WS2812, DATA_PIN, GRB>(leds, NUM_LEDS);
  FastLED.setBrightness(50); // 设置适中的亮度（0-255）

  // 初始化网络与 ESP-NOW
  initEspNowReceiver();

  // 状态 A：如果原本就处于“暂停休眠模式”
  if (keepAwakeMode)
  {
    Serial.println("Running in ALWAYS-AWAKE mode. Waiting for signals...");
    // 既然在线，确保灯珠是亮着的（比如绿色）
    leds[0] = CRGB::Green;
    FastLED.show();

    lastHeartbeatTime = millis();
    return;
  }

  // 状态 B：处于“周期唤醒探测”状态
  Serial.println("Woke up. Flashing window check...");
  heartbeatReceived = false;
  uint32_t startTime = millis();

  // 闪现监听 40ms
  while (millis() - startTime < WAKEUP_WINDOW_MS)
  {
    if (heartbeatReceived)
      break;
    delay(1);
  }

  if (heartbeatReceived)
  {
    // 抓到心跳，修改 RTC 变量
    keepAwakeMode = true;
    lastHeartbeatTime = millis();
    Serial.println("Transmitter detected! Switching to Always-Awake mode...");

    // 抓到心跳时点亮灯珠（绿色）
    leds[0] = CRGB::Green;
    FastLED.show();
  }
  else
  {
    // 没抓到心跳，立马调用带有“熄灯逻辑”的休眠函数
    Serial.println("No HB found in window.");
    enterDeepSleep();
  }

  wandServo.setOpenAngle(105); // 开灯角度
  wandServo.setCloseAngle(75); // 关灯角度
  wandServo.setRestAngle(90);  // 静止角度
  wandServo.setHoldTime(300);  // 保持 300ms
  wandServo.begin();
}

void loop()
{
  // 只有当 keepAwakeMode == true 时，程序才会持续运行在这里

  // 超时检测：如果 1 秒钟没收到心跳，则认为断线
  if (millis() - lastHeartbeatTime > KEEP_AWAKE_TIMEOUT_MS)
  {
    Serial.println("\n[TIMEOUT] Transmitter lost heartbeat! Returning to sleep-wake cycle...");
    keepAwakeMode = false;
    enterDeepSleep(); // 内部会自动熄灭灯珠并休眠
  }

  delay(100);
}

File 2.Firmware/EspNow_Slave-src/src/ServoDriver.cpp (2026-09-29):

#include "ServoDriver.h"

void ServoDriver::begin()
{
    xTaskCreate(
        taskFunc,
        "servo_task",
        2048,
        this,
        1,
        &taskHandle);
}

void ServoDriver::triggerOpen()
{
    if (taskHandle)
    {
        pendingAction = ACTION_OPEN;
        xTaskNotifyGive(taskHandle);
    }
}

void ServoDriver::triggerClose()
{
    if (taskHandle)
    {
        pendingAction = ACTION_CLOSE;
        xTaskNotifyGive(taskHandle);
    }
}

void ServoDriver::setRestAngle(uint8_t angle)
{
    restAngle = angle;
}

void ServoDriver::setOpenAngle(uint8_t angle)
{
    openAngle = angle;
}

void ServoDriver::setCloseAngle(uint8_t angle)
{
    closeAngle = angle;
}

void ServoDriver::setHoldTime(uint32_t ms)
{
    holdTimeMs = ms;
}

void ServoDriver::taskFunc(void *param)
{
    ServoDriver *driver = static_cast<ServoDriver *>(param);
    driver->taskLoop();
}

void ServoDriver::taskLoop()
{
    while (true)
    {
        // 阻塞等待 triggerOpen() / triggerClose() 通知
        ulTaskNotifyTake(pdTRUE, portMAX_DELAY);

        uint8_t targetAngle = (pendingAction == ACTION_OPEN) ? openAngle : closeAngle;

        servo.attach(SERVO_PIN);
        servo.write(restAngle);
        // 执行触发动作
        servo.write(targetAngle);
        vTaskDelay(pdMS_TO_TICKS(holdTimeMs));
        servo.write(restAngle);
        servo.detach();
    }
}

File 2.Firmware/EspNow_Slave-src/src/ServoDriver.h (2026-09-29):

#ifndef SERVO_DRIVER_H
#define SERVO_DRIVER_H

#include <Arduino.h>
#include <ESP32Servo.h>

#define SERVO_PIN 1 // GPIO pin for the servo

class ServoDriver
{
public:
    void begin();
    void triggerOpen();
    void triggerClose();

    void setRestAngle(uint8_t angle);
    void setOpenAngle(uint8_t angle);
    void setCloseAngle(uint8_t angle);
    void setHoldTime(uint32_t ms);

private:
    enum Action
    {
        ACTION_OPEN,
        ACTION_CLOSE
    };

    static void taskFunc(void *param);
    void taskLoop();

    Servo servo;
    TaskHandle_t taskHandle = nullptr;

    uint8_t restAngle = 0;
    uint8_t openAngle = 90;
    uint8_t closeAngle = 90;
    uint32_t holdTimeMs = 500;
    Action pendingAction = ACTION_OPEN;
};

#endif

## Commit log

2026-09-29 Init repo
    [0.csv, 1.csv, 2.csv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]
2026-09-29 完善视频链接
2026-09-29 增加立创开源平台链接
2026-10-23 补充魔杖热点连接密码说明
2026-11-03 删除旧手势模型原始数据
2026-11-03 文档和数据更新，以适配新发布的固件v2
2026-11-03 更新固件v2
2026-11-03 更新视频链接
2026-11-03 优化README段落
2026-11-11 文档更新
2026-11-11 更新固件v2.1
2026-11-11 更新文档以适配新的固件v2.1
